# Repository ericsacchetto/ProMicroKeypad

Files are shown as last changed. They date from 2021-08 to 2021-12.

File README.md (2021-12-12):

# ProMicroKeypad

The Pro Micro Keypad uses 9 switches to drive Windows shortcuts.
It is based on the Arduino Pro Micro (ATMega 32u4).

Nine Cherry MX Keys were used, turning on the corresponding LED for brief period of time once the ky is pressed.

A rotary encoder was included in order to easily control the volume.

The HID library https://github.com/NicoHood/HID was used, which provided an easy implementation of the shortcut key code.

All the schematic and PCB design were done using KiCad.



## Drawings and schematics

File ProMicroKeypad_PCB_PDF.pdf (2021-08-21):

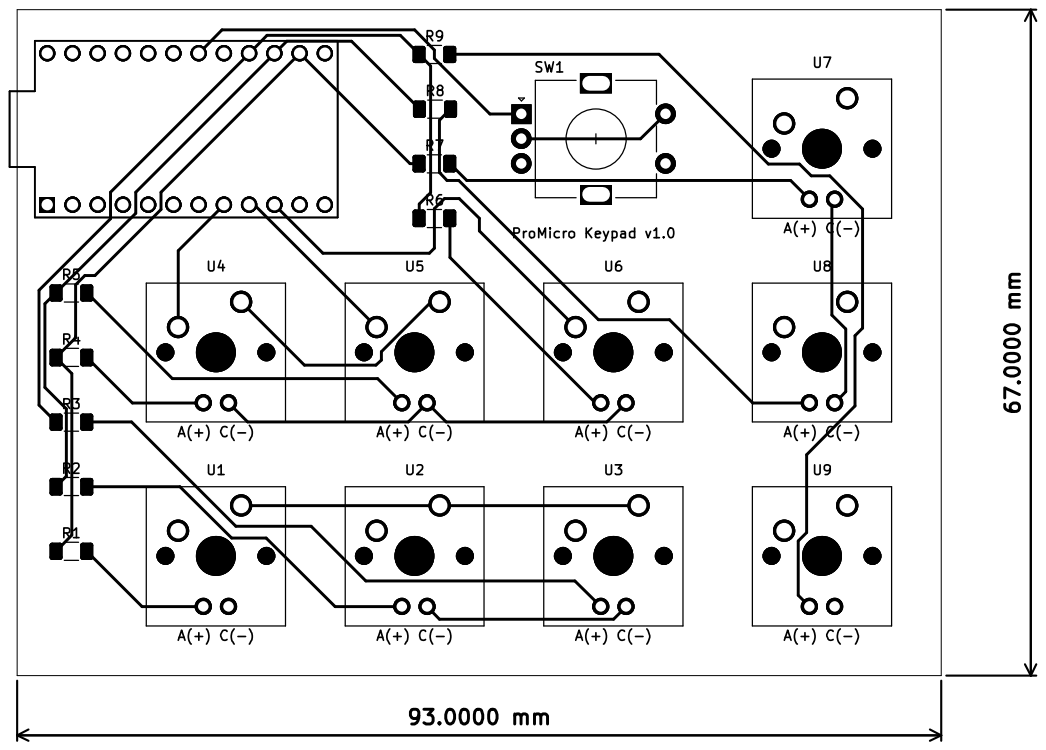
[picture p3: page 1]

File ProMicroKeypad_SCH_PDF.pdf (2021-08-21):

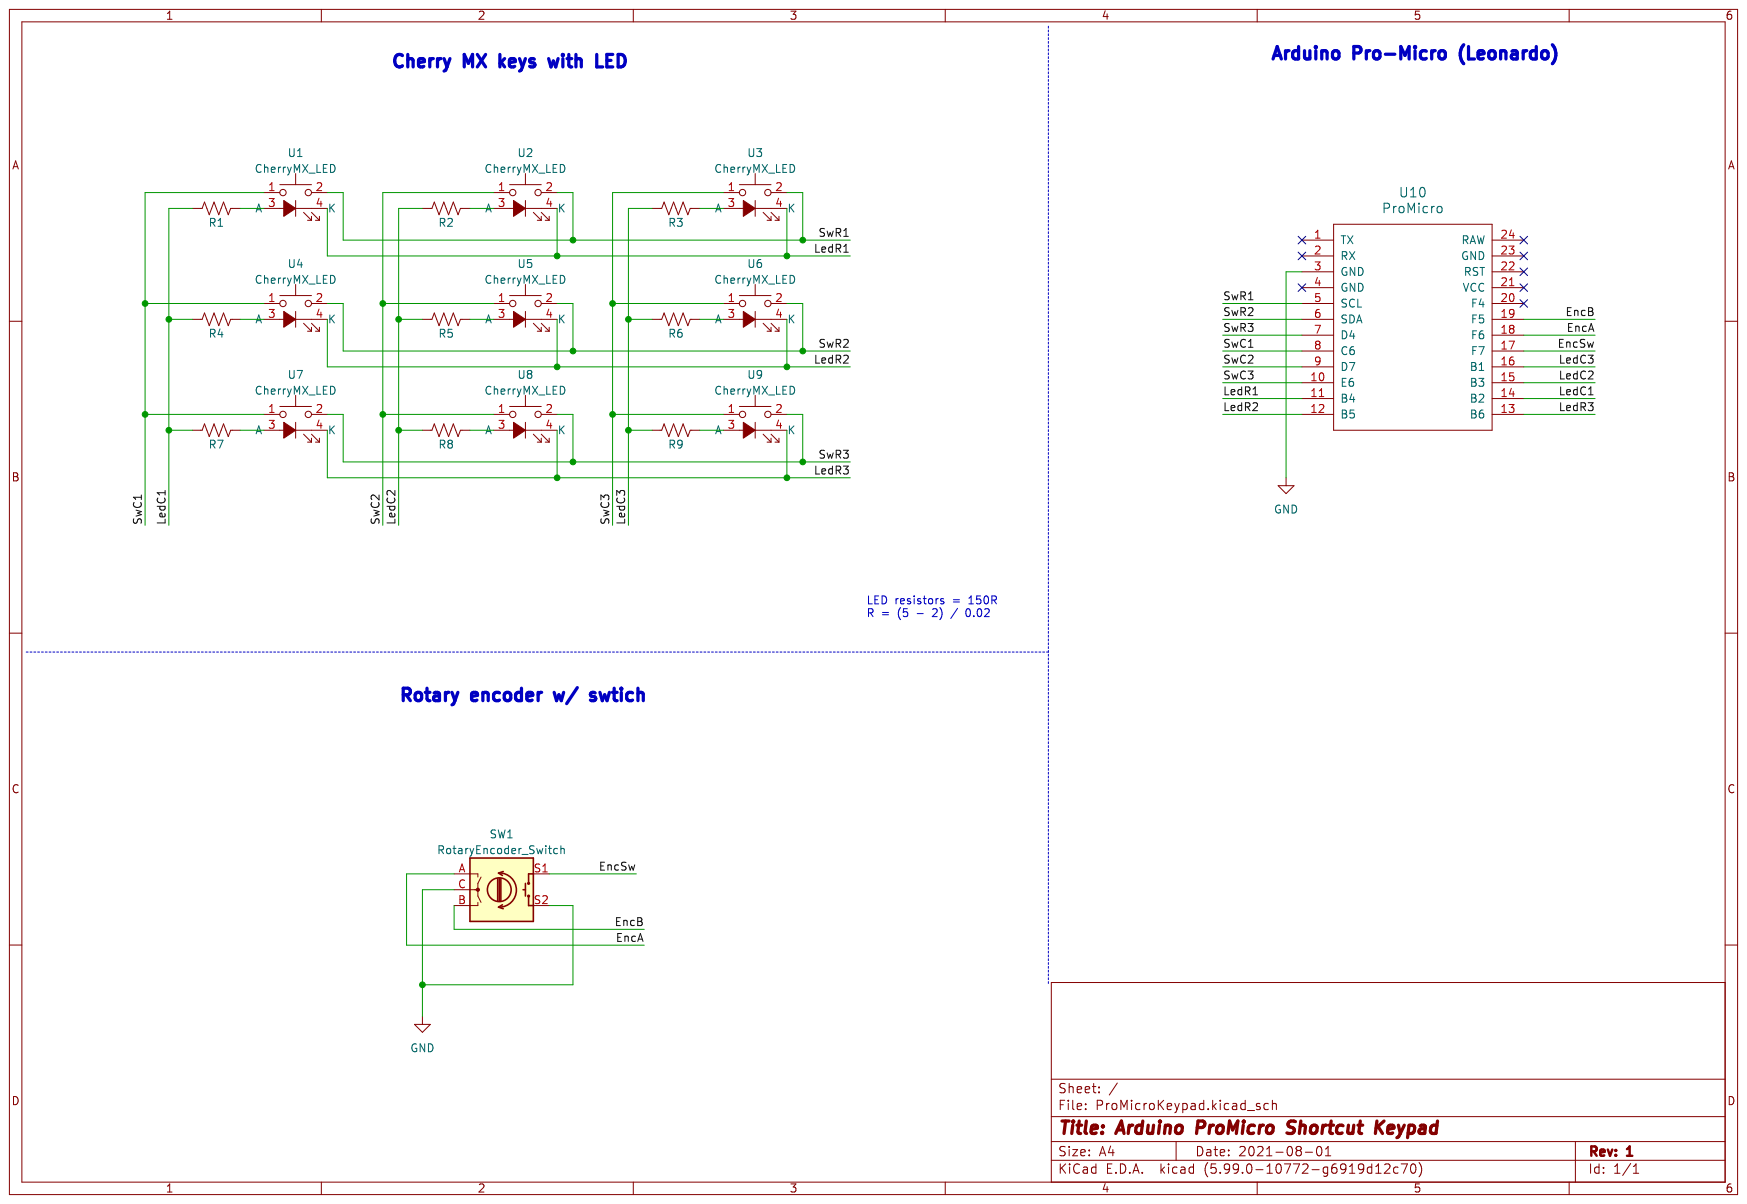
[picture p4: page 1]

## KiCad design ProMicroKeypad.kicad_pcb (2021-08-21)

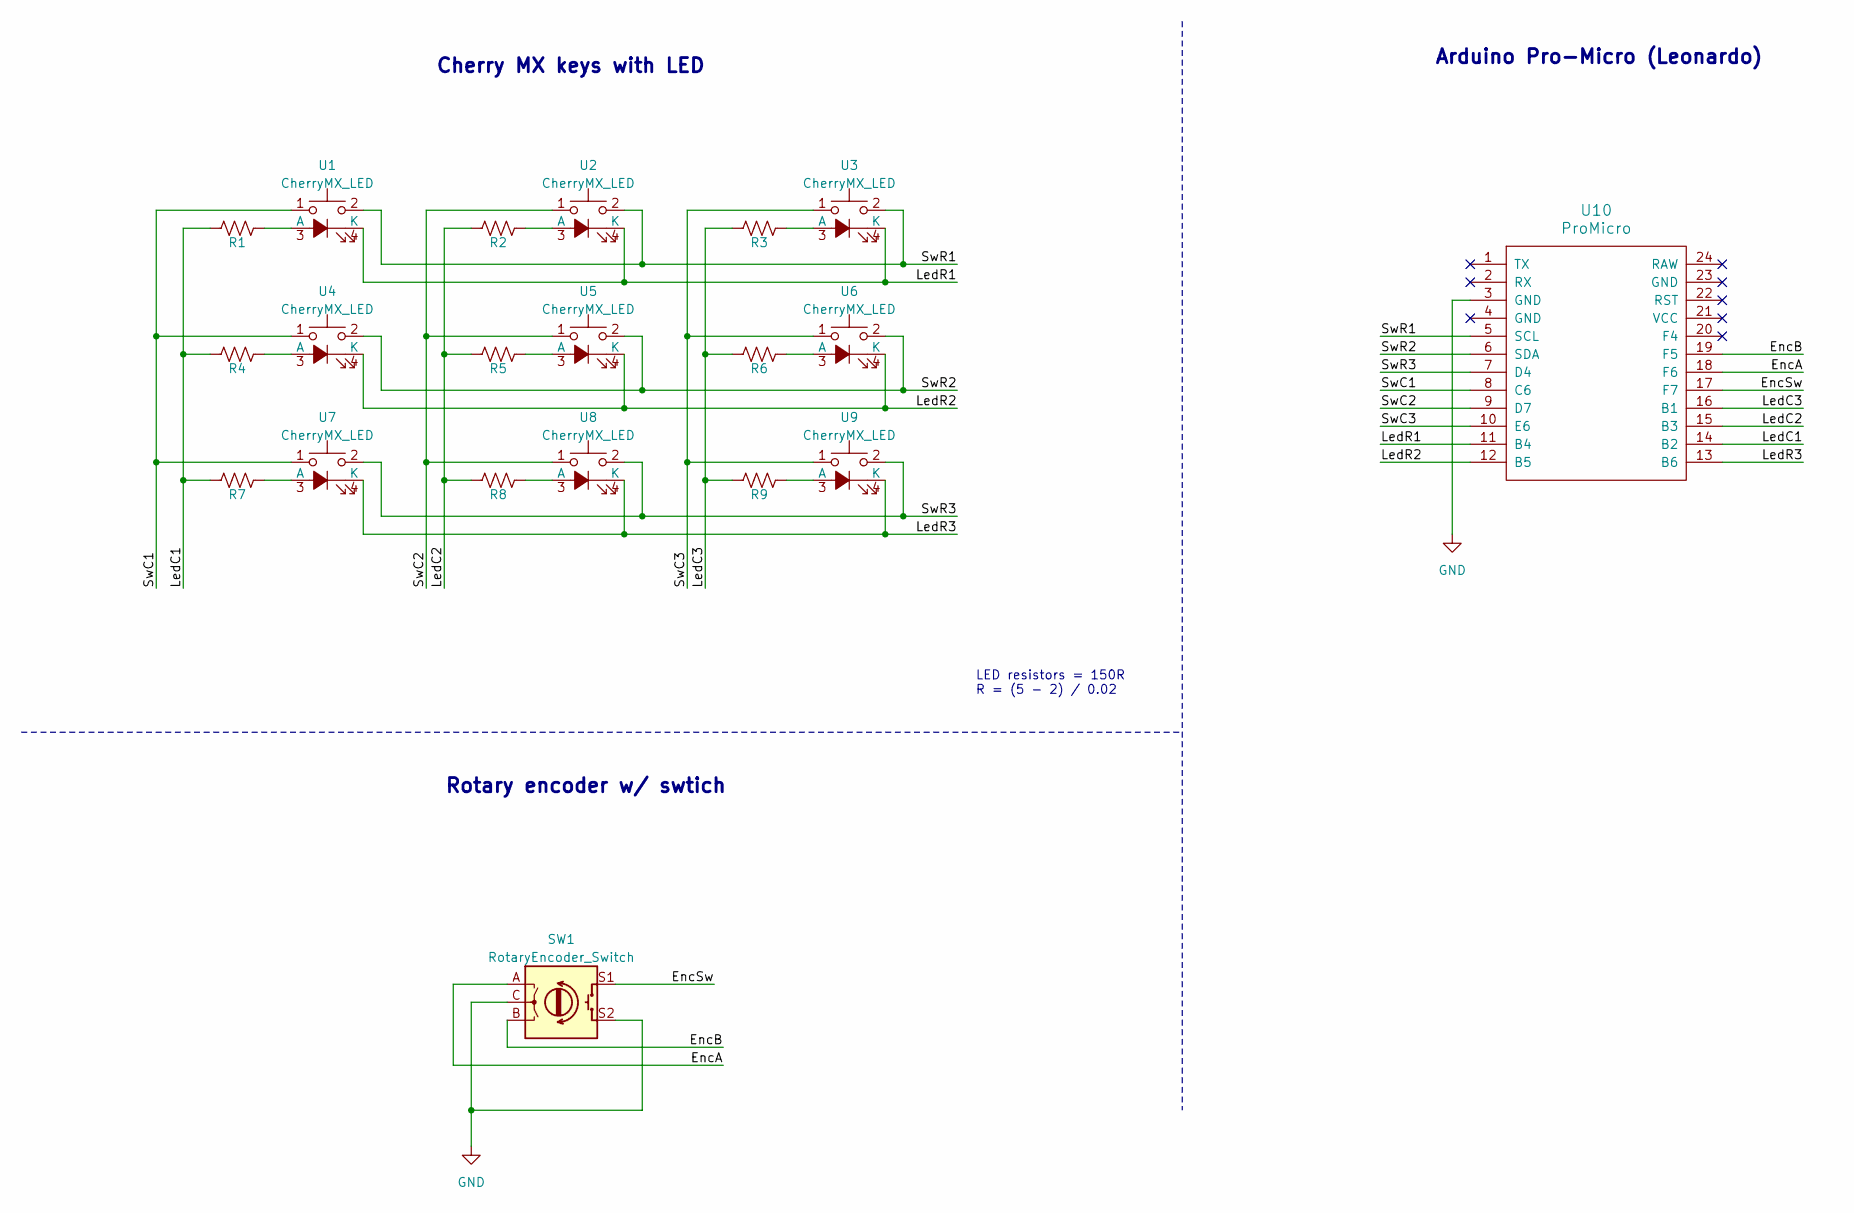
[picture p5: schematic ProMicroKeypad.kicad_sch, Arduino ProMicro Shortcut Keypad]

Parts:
R1, R2, R3, R4, R5, R6, R7, R8, R9: 150R; R_1206_3216Metric_Pad1.30x1.75mm_HandSolder
SW1: RotaryEncoder_Switch; RotaryEncoder_Alps_EC11E-Switch_Vertical_H20mm
U1, U2, U3, U4, U5, U6, U7, U8, U9: CherryMX_LED; CherryMX_1.00u_PCB_LED
U10: ProMicro

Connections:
/EncA: SW1.A, U10.18 (F6)
/EncB: SW1.B, U10.19 (F5)
/EncSw: SW1.S1, U10.17 (F7)
/LedC1: R1.1, R4.1, R7.1, U10.14 (B2)
/LedC2: R2.1, R5.1, R8.1, U10.15 (B3)
/LedC3: R3.1, R6.1, R9.1, U10.16 (B1)
/LedR1: U1.4 (A), U2.4 (A), U3.4 (A), U10.11 (B4)
/LedR2: U4.4 (A), U5.4 (A), U6.4 (A), U10.12 (B5)
/LedR3: U7.4 (A), U8.4 (A), U9.4 (A), U10.13 (B6)
/SwC1: U1.1, U4.1, U7.1, U10.8 (C6)
/SwC2: U2.1, U5.1, U8.1, U10.9 (D7)
/SwC3: U3.1, U6.1, U9.1, U10.10 (E6)
/SwR1: U1.2, U2.2, U3.2, U10.5 (SCL)
/SwR2: U4.2, U5.2, U6.2, U10.6 (SDA)
/SwR3: U7.2, U8.2, U9.2, U10.7 (D4)
GND: SW1.C, SW1.S2, U10.3 (GND)
unnamed: R1.2, U1.3 (K)
unnamed: R2.2, U2.3 (K)
unnamed: R3.2, U3.3 (K)
unnamed: R4.2, U4.3 (K)
unnamed: R5.2, U5.3 (K)
unnamed: R6.2, U6.3 (K)
unnamed: R7.2, U7.3 (K)
unnamed: R8.2, U8.3 (K)
unnamed: R9.2, U9.3 (K)

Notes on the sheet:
Cherry MX keys with LED
Rotary encoder w/ swtich
LED resistors = 150R R = (5 - 2) / 0.02
Arduino Pro-Micro (Leonardo)

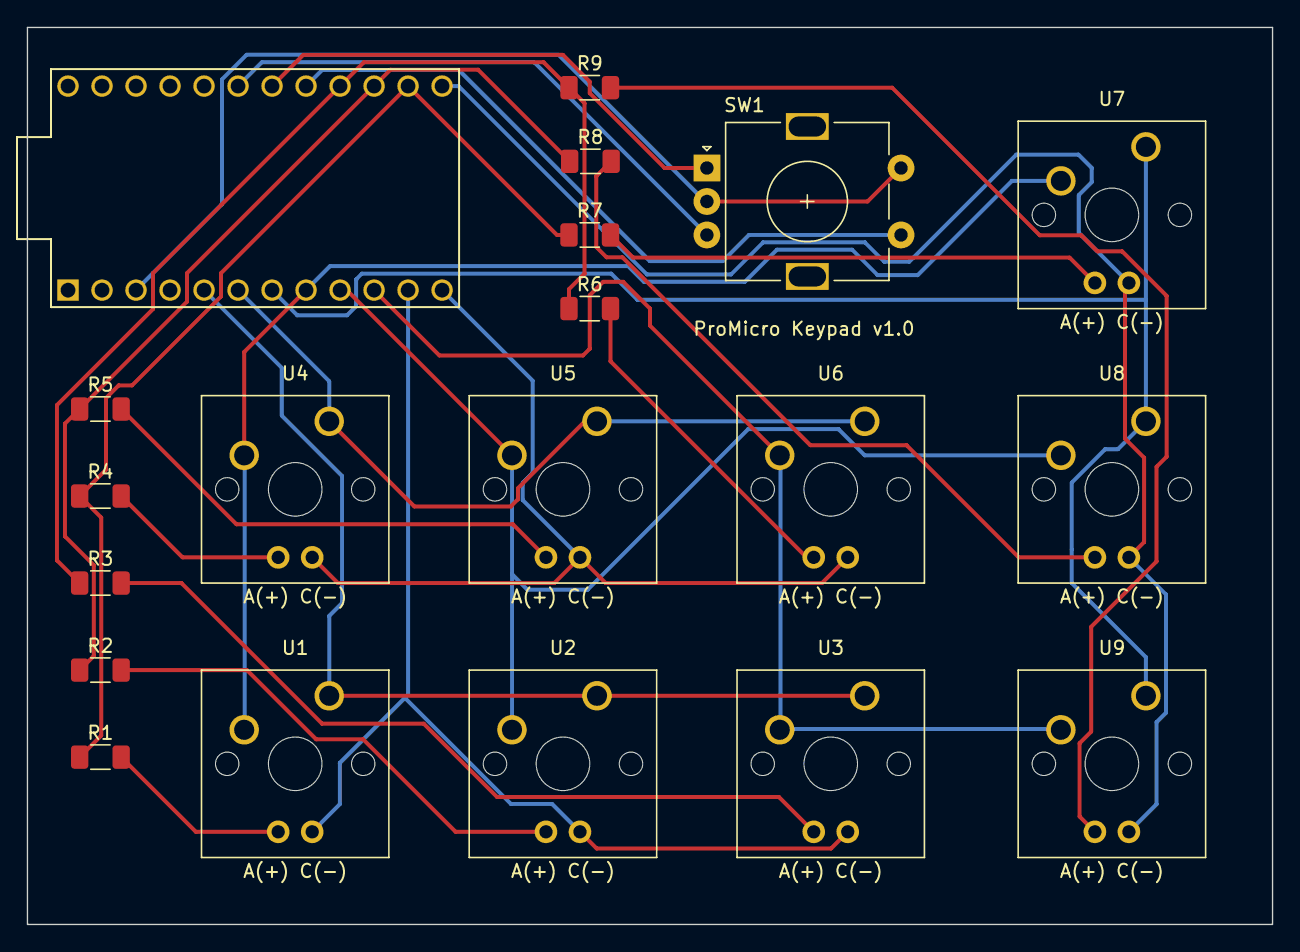
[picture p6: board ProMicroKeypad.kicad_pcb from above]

Board: 2 copper layers, 93.0 x 67.0 mm, 20 parts (0 on the bottom side), 25 nets.

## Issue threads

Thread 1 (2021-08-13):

Add PCB PDF

ericsacchetto, 2021-08-13:
The PCB PDF file is missing.

ericsacchetto, 2021-08-13:
Done

Closed 2021-08-13.

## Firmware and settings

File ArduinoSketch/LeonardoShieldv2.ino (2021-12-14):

#include <Keypad.h>
#include "HID-Project.h"


// Rotary Encoder Inputs
#define Clock A1
#define Data A2
#define Push A0
int counter = 0;
int currentStateClock;
int lastStateClock;
String currentDir ="";
unsigned long lastButtonPress = 0;

#define NUM_LED_COLS (3)            // Number of LED columns (+, anode)
#define NUM_LED_ROWS (3)            // Number of LED rows (-, cathode)

const byte ROWS = 3;
const byte COLS = 3;

char hexaKeys[ROWS][COLS] = {
  {'1', '2', '3'},
  {'4', '5', '6'},
  {'7', '8', '9'},
  };

byte rowPins[ROWS] = {2, 3, 4}; 
byte colPins[COLS] = {5, 6, 7}; 
static const uint8_t ledRowPins[NUM_LED_ROWS] = {8, 9, 10};     // Pins connected to LED rows (-)
static const uint8_t ledColPins[NUM_LED_COLS] = {16, 14, 15};   // Pins connected to LED cols (+)
static bool LED_buffer[NUM_LED_COLS][NUM_LED_ROWS];             // Keeps track of LED states

Keypad customKeypad = Keypad(makeKeymap(hexaKeys), rowPins, colPins, ROWS, COLS); 

void setup(){
  Serial.begin(9600);
  Consumer.begin();
  Keyboard.begin();

  setupLEDPins();

  pinMode(Clock,INPUT_PULLUP);
  pinMode(Data,INPUT_PULLUP);
  pinMode(Push, INPUT_PULLUP);
  lastStateClock = digitalRead(Clock);

  for (uint8_t i = 0; i < NUM_LED_COLS; i++)
  {
    for (uint8_t j = 0; j < NUM_LED_ROWS; j++)
    {
      LED_buffer[i][j] = 0;
    }
  }
}

static void setupLEDPins()
{
  uint8_t i;
  // LED drive rows - written LOW when active, HIGH otherwise
  for (i = 0; i < NUM_LED_ROWS; i++)
  {
    pinMode(ledRowPins[i], OUTPUT);
    digitalWrite(ledRowPins[i], HIGH);
  }

  // LED select columns - Write HIGH to turn an LED on.
  for (i = 0; i < NUM_LED_COLS; i++)
  {
    pinMode(ledColPins[i], OUTPUT);
    digitalWrite(ledColPins[i], LOW);
  }
}

void LightLED(int c, int r)
{
  digitalWrite(ledColPins[c], HIGH);
  digitalWrite(ledRowPins[r], LOW);
  delay(500);
}

void OpenApp(String appAddress)
{
  Keyboard.press(KEY_LEFT_CTRL);
  Keyboard.press(KEY_ESC);
  delay(100);
  Keyboard.releaseAll();
  Keyboard.print(appAddress);
  delay(100);
  Keyboard.press(KEY_RETURN);
  Keyboard.releaseAll();
}
  
void loop(){
  char customKey = customKeypad.getKey();
  currentStateClock = digitalRead(Clock);

  if (currentStateClock != lastStateClock  && currentStateClock == 1)
  {
    if (digitalRead(Data) != currentStateClock)
    {
      counter --;
      Consumer.write(MEDIA_VOLUME_DOWN);
    } 
    else 
    {
      counter ++;
      Consumer.write(MEDIA_VOLUME_UP);
    }
  }
  lastStateClock = currentStateClock;

  int btnState = digitalRead(Push);

  if (btnState == LOW) 
  {
    if (millis() - lastButtonPress > 50) {
      Consumer.write(MEDIA_VOLUME_MUTE);
    }
    lastButtonPress = millis();
  }

    
  switch (customKey) 
  {
  case '1':  
    Consumer.write(MEDIA_PREVIOUS);
    LightLED(0,0);
    break;
  case '2':
    Consumer.write(MEDIA_PLAY_PAUSE);
    LightLED(1,0);
    break;
  case '3':
    Consumer.write(MEDIA_NEXT);
    LightLED(2,0);
    break;
  case '4':
    Keyboard.write(KEY_PRINTSCREEN);
    LightLED(0,1);
    break;
  case '5':
    Keyboard.press(KEY_LEFT_WINDOWS);
    Keyboard.press(KEY_L);
    Keyboard.releaseAll();
    LightLED(1,1);
    break;
  case '6':
    Keyboard.write(KEY_MENU);
    LightLED(2,1);
    break;
  case '7':
    OpenApp("Your App 1");  //replace with your favorite app
    LightLED(0,2);
    break;
  case '8':
    OpenApp("Your App 2");  //replace with your second favorite app
    LightLED(1,2);
    break;
  case '9':
    OpenApp("spotify");
    LightLED(2,2);
    break;
  }
  setupLEDPins();
}

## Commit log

2021-08-11 Components added
    [ProMicroKeypad.kicad_sch]
2021-08-11 Finished component placement and annotation
    [ProMicroKeypad.kicad_sch]
2021-08-11 Footprints assigned
    [ProMicroKeypad.kicad_sch]
2021-08-11 PCB design done
    [ProMicroKeypad.kicad_pcb, ProMicroKeypad.kicad_sch]
2021-08-11 Board completed
    [ProMicroKeypad-B_Adhesive.gbr, ProMicroKeypad-B_Cu.gbr, ProMicroKeypad-B_Fab.gbr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]
2021-08-13 Uploaded the PCB PDF
2021-08-21 Fixing schematic and PCB
    [ProMicroKeypad.kicad_pcb, ProMicroKeypad.kicad_sch]
2021-08-22 Adding Arduino Pro code
